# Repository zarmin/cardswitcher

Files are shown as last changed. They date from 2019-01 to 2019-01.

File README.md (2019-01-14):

# Card switcher

In some cases physical switching of a smart card is required to operate / test a system, this project can change between multiple smart cards electronically.

The device can be managed via a USB interface (Serial bus over USB).

_The project is inspired by [Smart Card removinator project](https://github.com/nkinder/smart-card-removinator)._

# Hardware

The device is made up from 3 different components: card shield, card controller, card adapter

## Card shield

One device installation can use multiple card shields, one card shield can take one card. The maximum number of stackable card shields are 15 (or 16, but w/o a unselected option). These shields are vertically stacked pcb modules.

Every shield have a 4 bit address, which can be changed by a dip switch on the board (the space between the stacked modules are enough to change the address after it stacked with a tweezer). The controller can detect address collisions via a feedback resistor.

Card shields can't detect if they have an inserted card or not.

### Card shield schematics

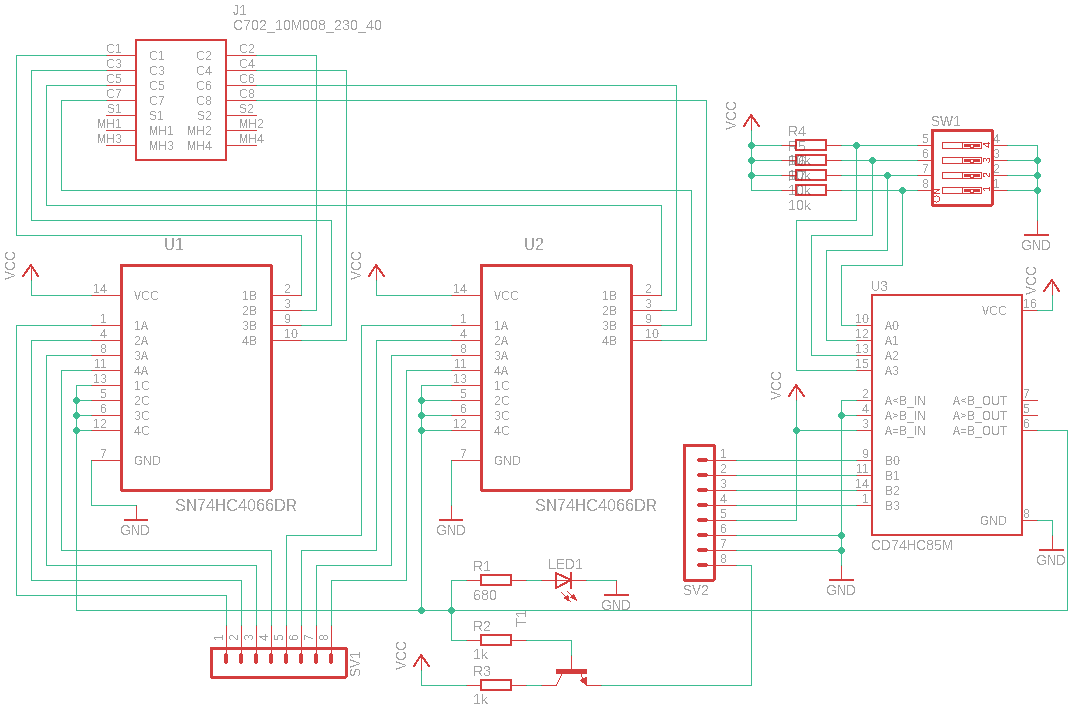
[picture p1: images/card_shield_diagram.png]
Card shield schematics


### Card shield PCB

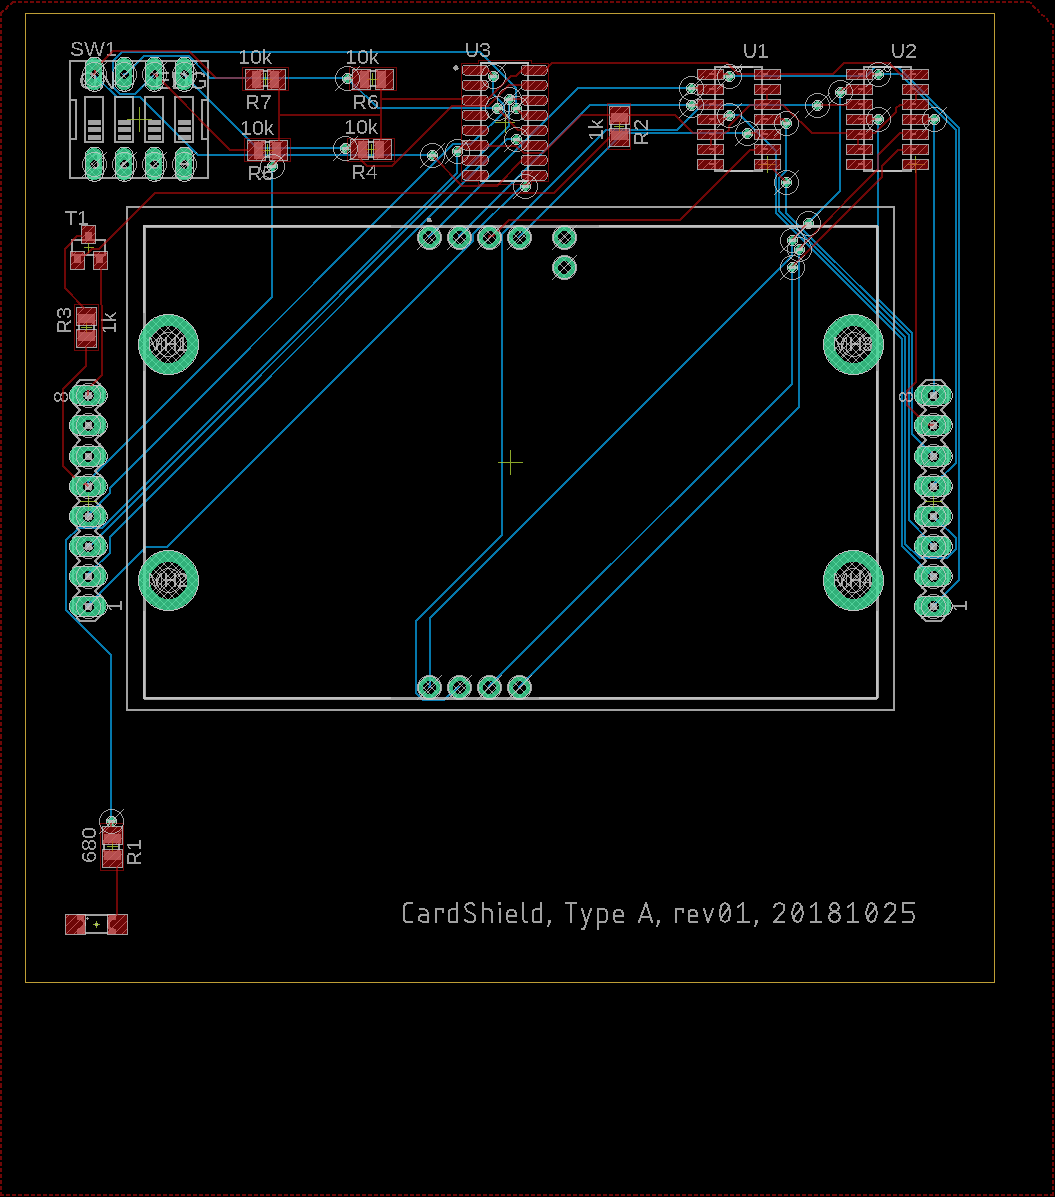
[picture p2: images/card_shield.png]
Card shield PBC


### Card shield photos

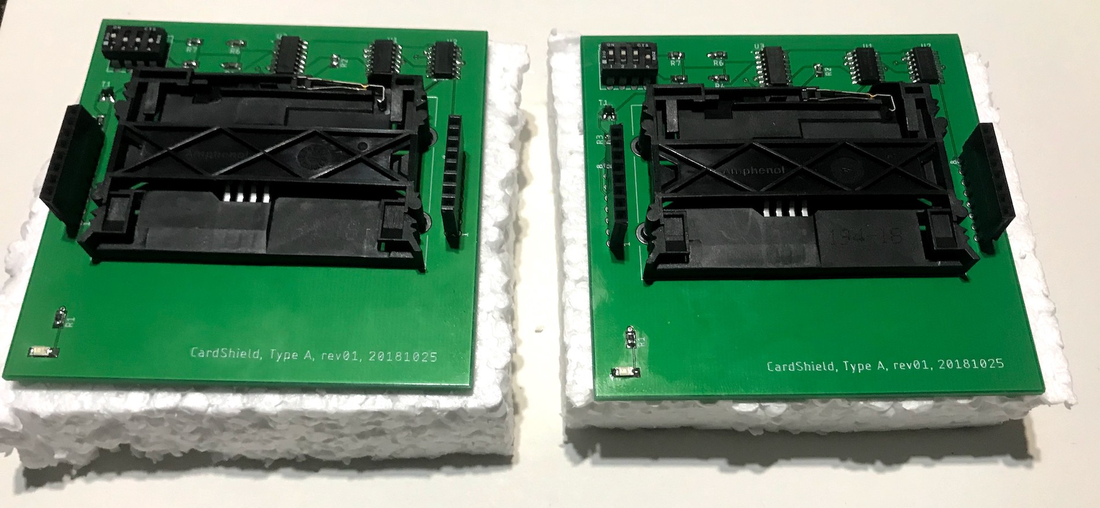
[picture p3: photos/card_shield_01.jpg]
Card shield photo


## Card controller

One device installation needs one controller. The controller will the base of the card shields.

The card controller can be controller (and powered) via mini USB. It connects to the card adapter with a ethernet cable (but not ethernet protocol of course).

It has an IC socket, initially designed to hold an ATMEGA168PA, with an Arduino software. The board also has a ISP connector to program the MCU.

### Card controller schematics

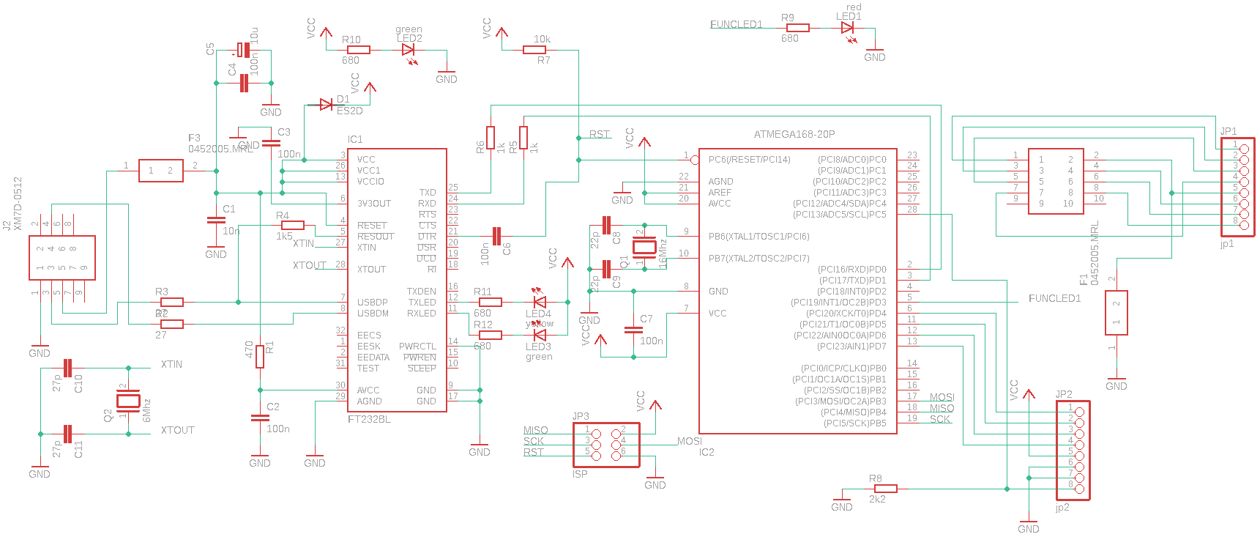
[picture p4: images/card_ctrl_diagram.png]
Card controller schematics


### Card controller PCB

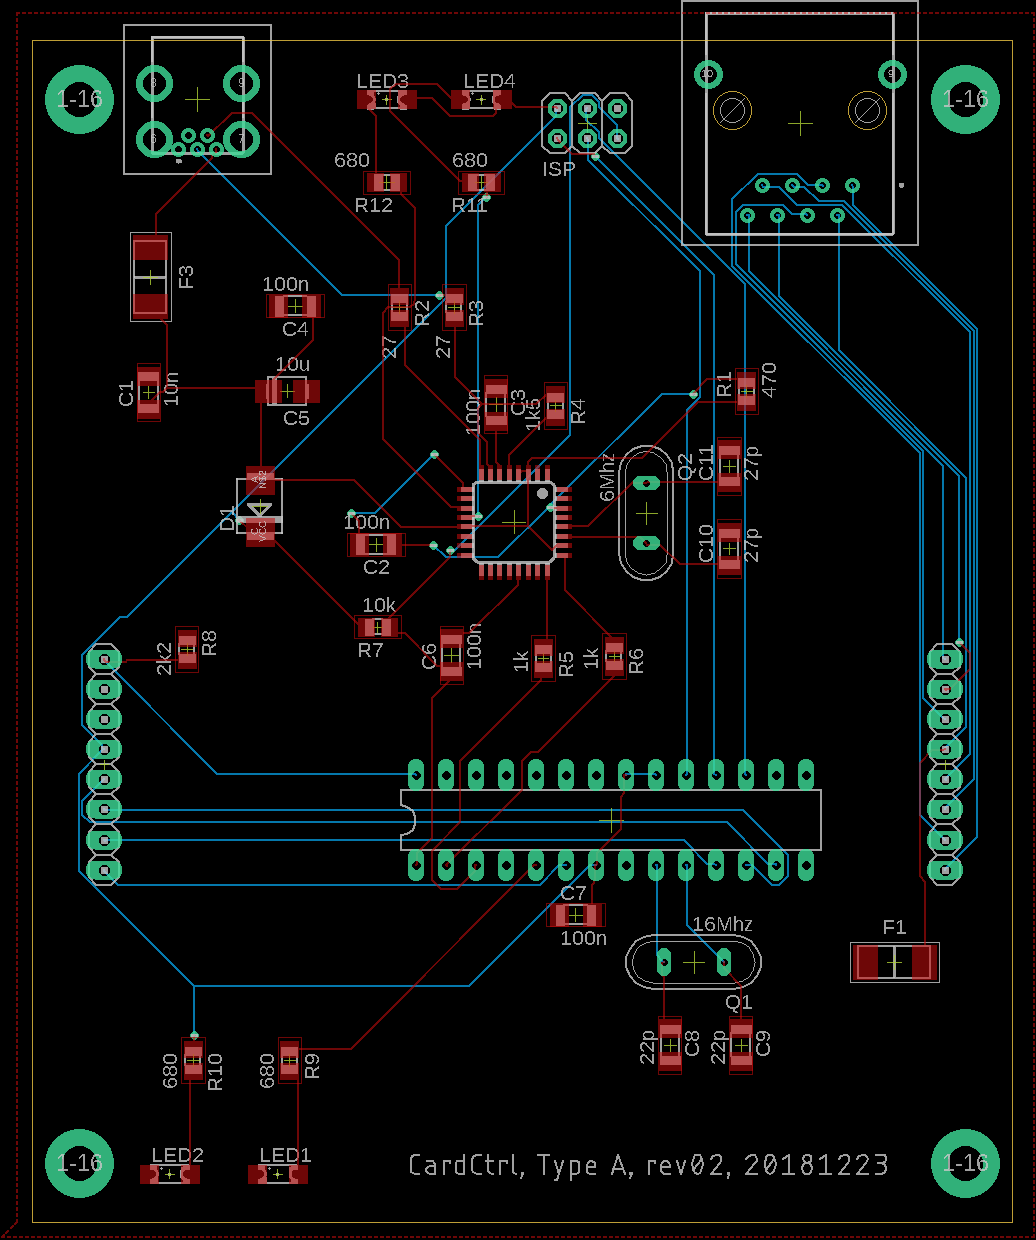
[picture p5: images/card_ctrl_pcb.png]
Card controller PCB


### Card controller photos

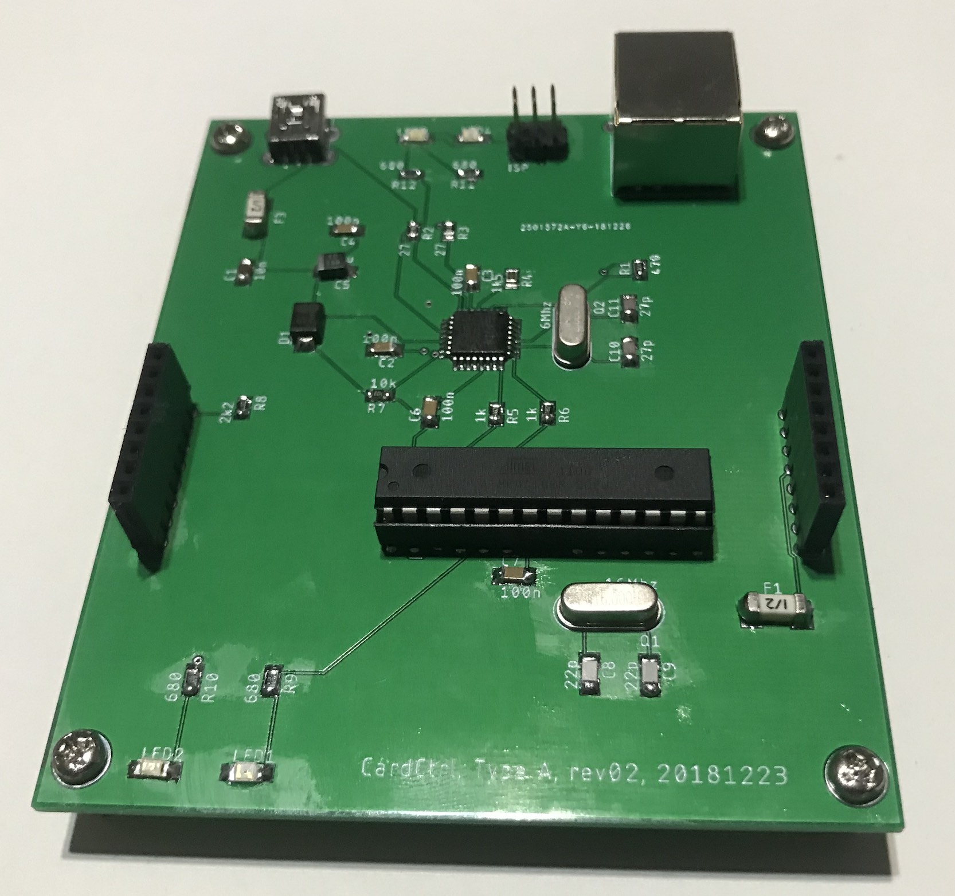
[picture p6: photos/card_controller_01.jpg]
Card controller photo

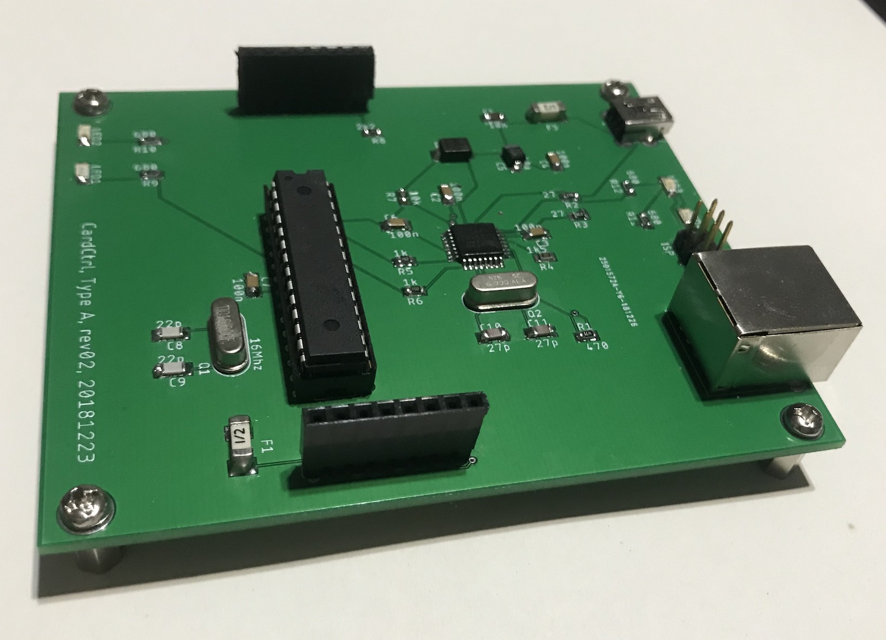
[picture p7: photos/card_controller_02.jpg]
Card controller photo


## Card adapter

The card adapter is the _fake_ card, that goes into the real card slot.

### Card adapter PCB

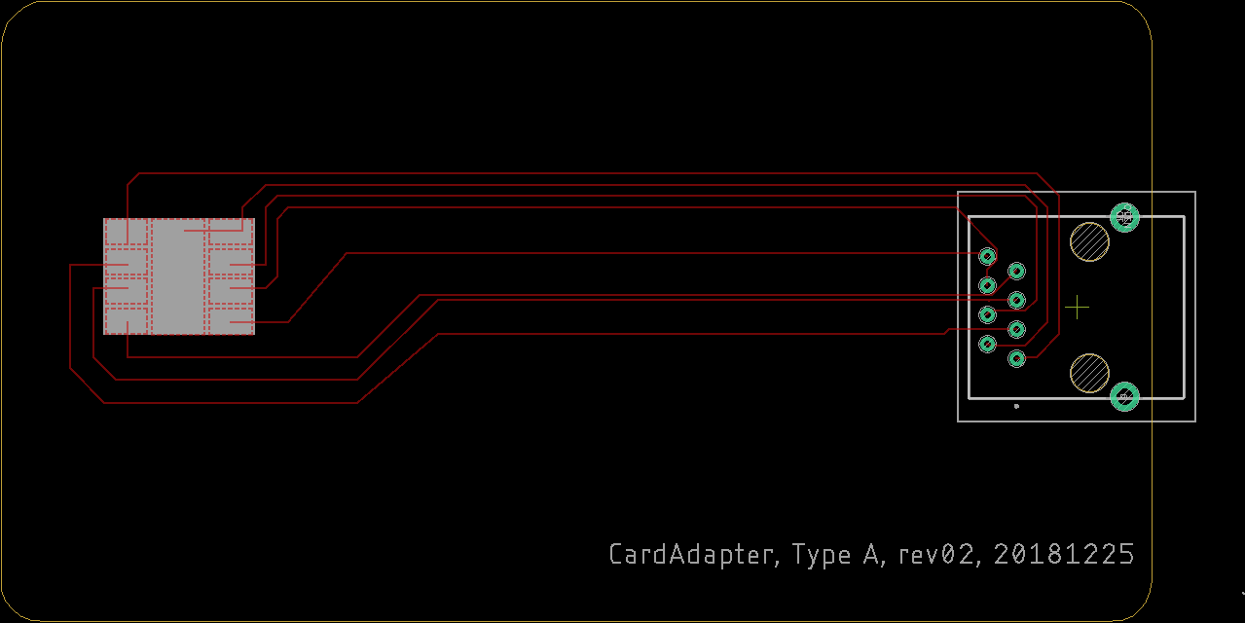
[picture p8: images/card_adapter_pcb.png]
Card adapter


### Card adapter photos

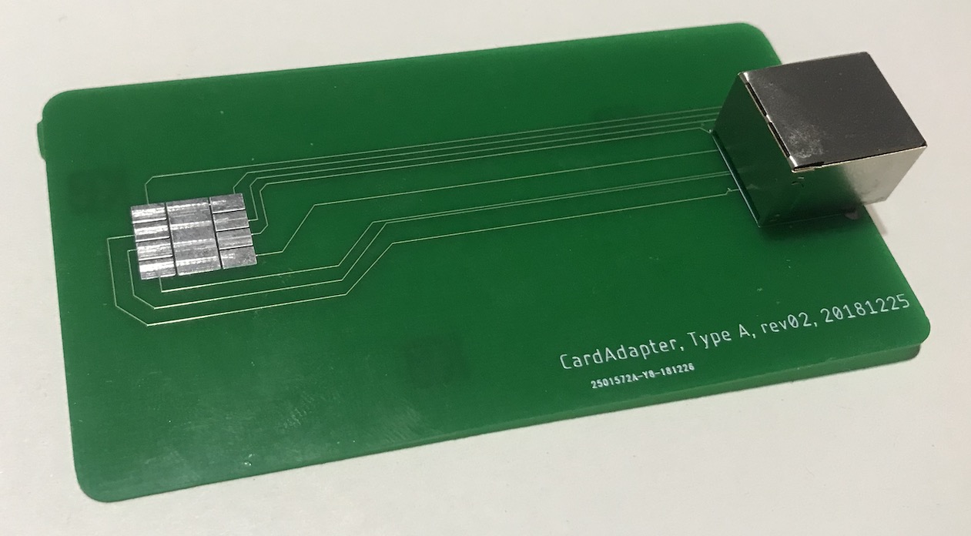
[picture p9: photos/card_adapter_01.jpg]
Card adapter photo

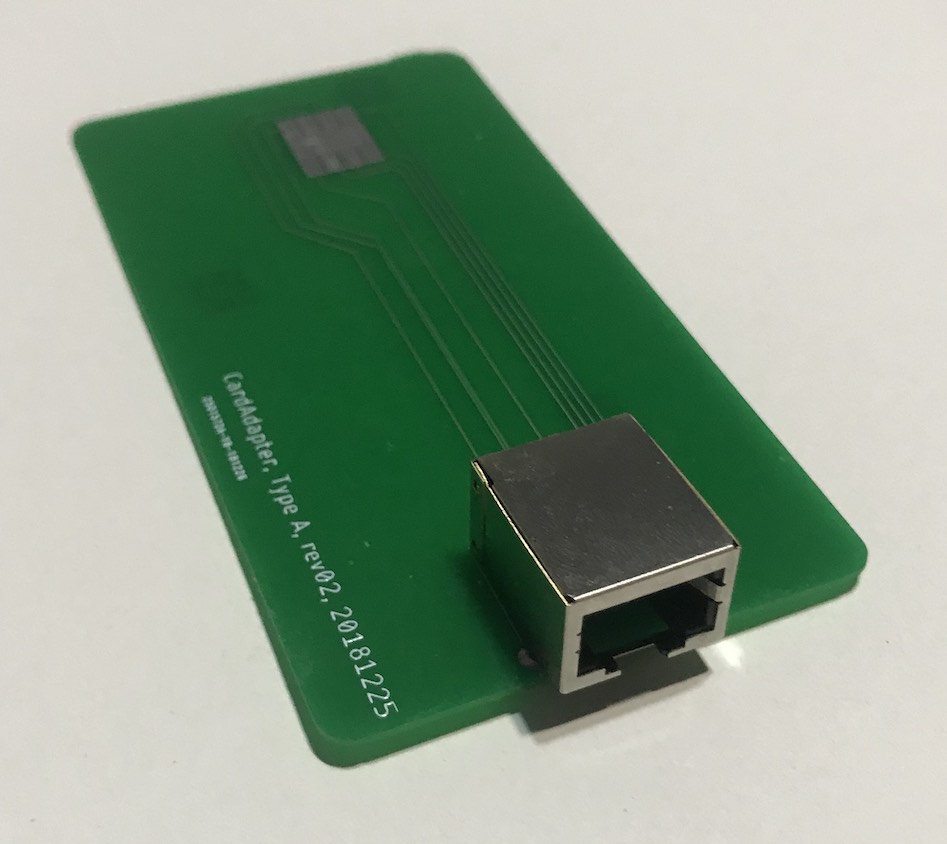
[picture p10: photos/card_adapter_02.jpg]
Card adapter photo


# Software

Software is in the mcu-software folder as an Arduino project. It can be uploaded via the USB interface or via the ISP. For the development the MiniCore Arduino board library used for the ATMega168IC (16 Mhz external clock; 168P / 168PA variant).

The software is checking the available card shield addresses upon boot and refuse to start (reboot loop with fast blinking of the activity LED) if an address collision is detected.
After the boot, it can be controlled via serial (via USB), by writing the addresses in ASCII (no newline required).

# Photos

_Installation with two card shield modules and cards_

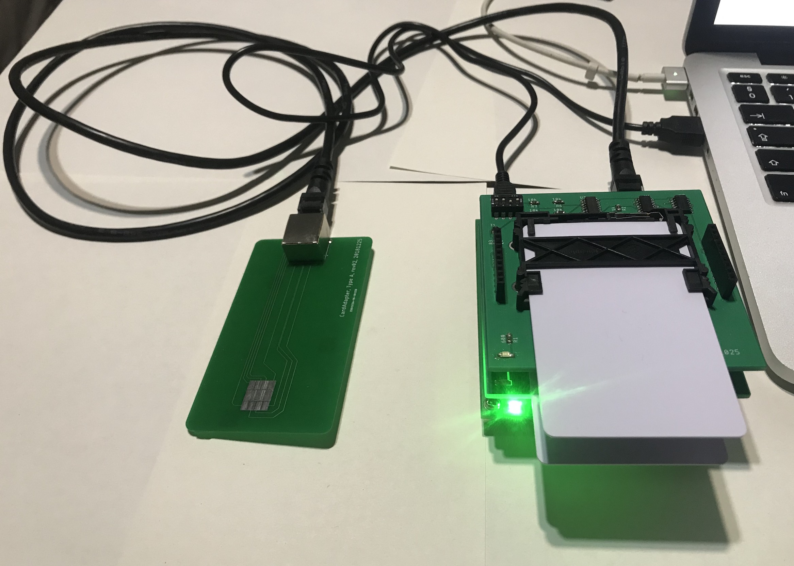
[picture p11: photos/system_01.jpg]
System with 2 cards

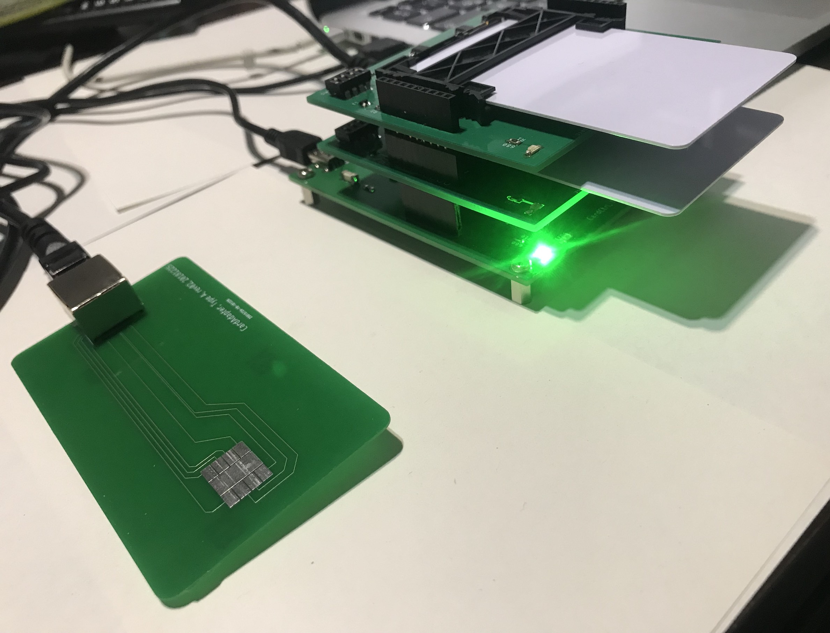
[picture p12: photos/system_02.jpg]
System with 2 cards

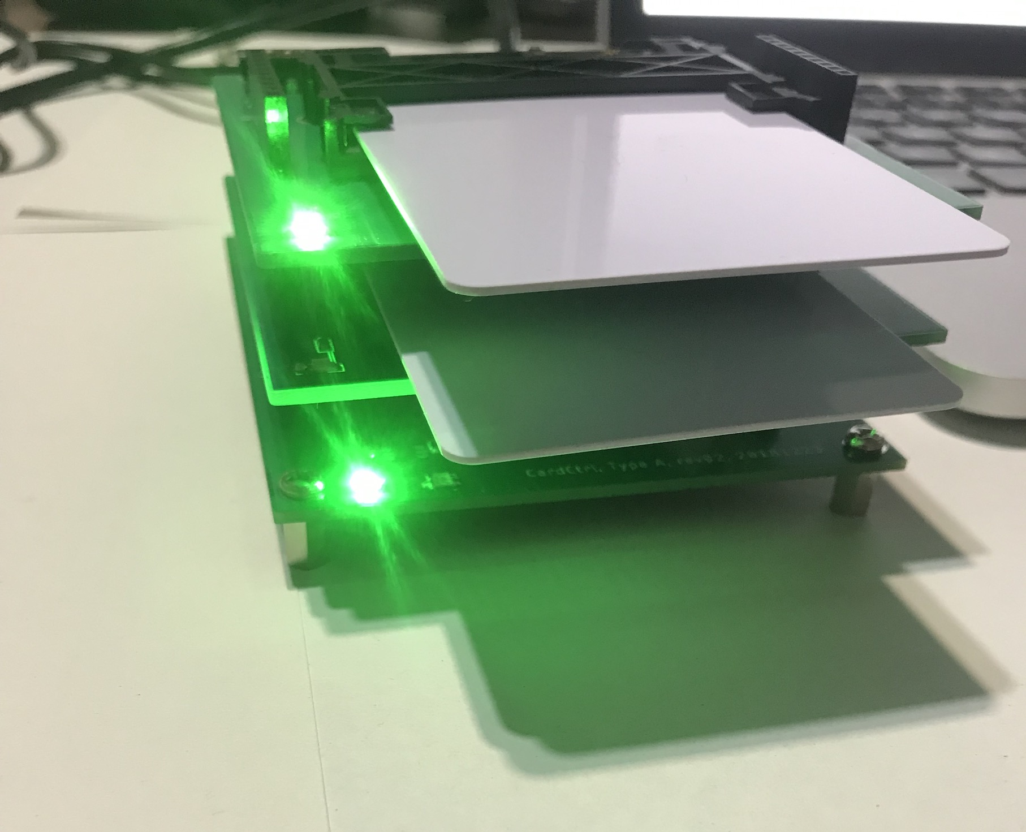
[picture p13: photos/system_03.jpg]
System with 2 cards


## Example terminal communication

```
Serial init
Device found on address: 1
Device found on address: 2
Ready to use!
Address? >>
Set to address (no active device): 4
Address? >>
Set to address (active device): 1
Address? >>
Set to address (active device): 2
Address? >>
```

# Components

The EAGLE files are containing the required components numbers (extra component libraries also included).

Special (non common / passive) components are:
- card shield: 2x SN74HC4066DR Quadruple Bilateral Analog Switch
- card shield: 1x CD74HC85M CMOS Logic 4-Bit Magnitude Comparator
- card shield: 1x C702 10M008 230 40 Amphenol Tuchel Smard card connector (Mouser)
- card controller: 1x FT232BL FTDI IC
- card controller: 1x ATMEGA168PA MCU

Every other component can be found in bom folder, or can be exported from EAGLE files.

# Isolation

The device using a common fused (500 mA) ground between the USB and the smart card adapter (Smart card connector GND). 

If complete isolation is required then an USB isolator (eg. Adafruit USB Isolator) can be used. The device should draw under 80 mA.

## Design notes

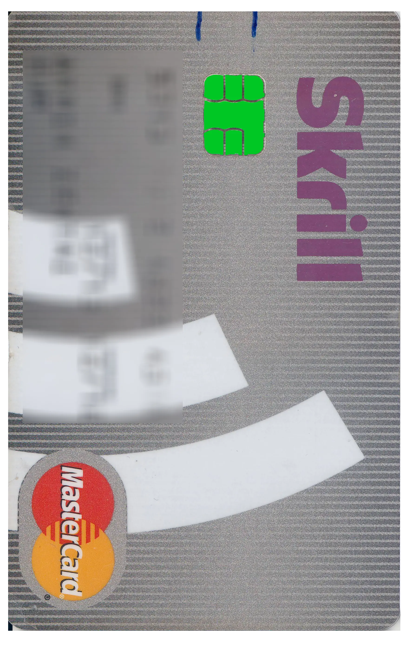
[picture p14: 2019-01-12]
cardmasks/base.webp

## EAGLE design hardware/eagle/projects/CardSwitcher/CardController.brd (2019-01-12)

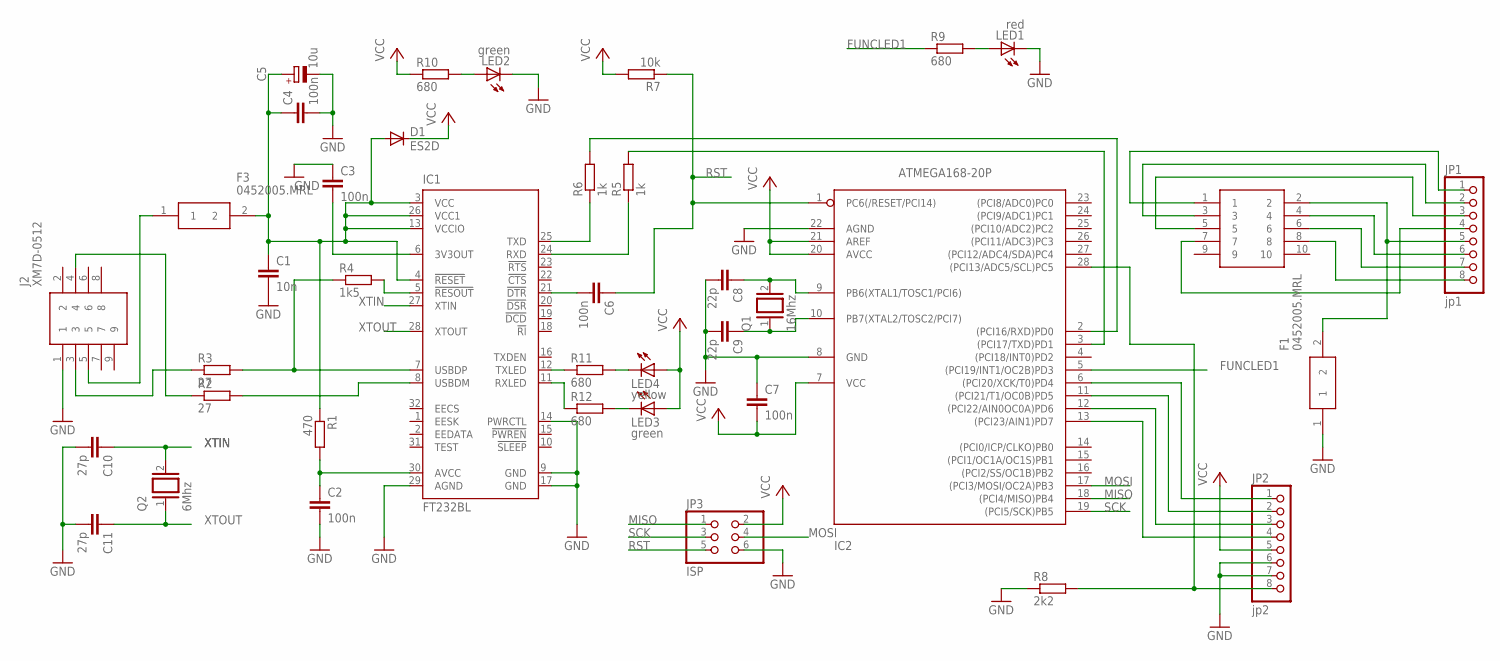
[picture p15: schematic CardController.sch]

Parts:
C1: 10n; C1206
C2, C3, C4, C6, C7: 100n; C1206
C5: 10u; B/3528-21W
C8, C9: 22p; C1206
C10, C11: 27p; C1206
D1: ES2D; SMB
F1, F3: 0452005.MRL; FUSC6127X294N
IC1: FT232BL; LQFP32-7X7
IC2: ATMEGA168-20P; DIL28-3
J1: 615008140121
J2: XM7D-0512; XM7D0512
JP1: jp1; 1X08
JP2: jp2; 1X08
JP3: ISP; 2X03
LED1: red; SML1206
LED2, LED3: green; SML1206
LED4: yellow; SML1206
Q1: 16Mhz; QS
Q2: 6Mhz; QS
R1: 470; R0805
R2, R3: 27; R0805
R4: 1k5; R0805
R5, R6: 1k; R0805
R7: 10k; R0805
R8: 2k2; R0805
R9, R10, R11, R12: 680; R0805

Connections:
FUNCLED1: IC2.5 ((PCI19/INT1/OC2B)PD3), R9.1
GND: C1.2, C2.2, C3.1, C4.2, C5.-, C7.1, C8.2, C9.2, C10.2, C11.2, F1.1, IC1.9 (GND), IC1.14 (PWRCTL), IC1.17 (GND), IC1.29 (AGND), IC2.8 (GND), IC2.22 (AGND), J2.1, JP2.6, JP2.7, JP3.6, LED1.C, LED2.C, R8.1
MISO: IC2.18 ((PCI4/MISO)PB4), JP3.1
MOSI: IC2.17 ((PCI3/MOSI/OC2A)PB3), JP3.4
unnamed: F3.1, J2.5
unnamed: C1.1, C4.1, C5.+, D1.A, F3.2, IC1.3 (VCC), IC1.4 (!RESET), IC1.13 (VCCIO), IC1.26 (VCC1), R1.1
unnamed: C2.1, IC1.30 (AVCC), R1.2
unnamed: C3.2, IC1.6 (3V3OUT)
unnamed: J2.4, R2.1
unnamed: IC1.8 (USBDM), R2.2
unnamed: J1.3, JP1.2
unnamed: IC1.5 (!RESOUT), R4.2
unnamed: IC1.25 (TXD), R6.1
unnamed: IC2.2 ((PCI16/RXD)PD0), R6.2
unnamed: IC2.13 ((PCI23/AIN1)PD7), JP2.4
unnamed: IC1.24 (RXD), R5.1
unnamed: C6.2, IC1.21 (!DTR)
unnamed: IC2.12 ((PCI22/AIN0OC0A)PD6), JP2.3
unnamed: C8.1, IC2.9 (PB6(XTAL1/TOSC1/PCI6)), Q1.2
unnamed: C9.1, IC2.10 (PB7(XTAL2/TOSC2/PCI7)), Q1.1
unnamed: IC2.28 ((PCI13/ADC5/SCL)PC5), JP2.8, R8.2
unnamed: IC1.12 (TXLED), R11.1
unnamed: LED1.A, R9.2
unnamed: J1.1, JP1.1
unnamed: IC2.3 ((PCI17/TXD)PD1), R5.2
unnamed: IC2.11 ((PCI21/T1/OC0B)PD5), JP2.2
unnamed: IC2.6 ((PCI20/XCK/T0)PD4), JP2.1
unnamed: J1.5, JP1.3
unnamed: J1.7, JP1.4
unnamed: F1.2, J1.2, JP1.5
unnamed: J1.4, JP1.6
unnamed: J1.6, JP1.7
unnamed: J1.8, JP1.8
unnamed: J2.3, R3.1
unnamed: LED2.A, R10.2
unnamed: IC1.11 (RXLED), R12.1
unnamed: LED4.C, R11.2
unnamed: LED3.C, R12.2
unnamed: IC1.7 (USBDP), R3.2, R4.1
RST: C6.1, IC2.1 (PC6(/RESET/PCI14)), JP3.5, R7.1
SCK: IC2.19 ((PCI5/SCK)PB5), JP3.3
VCC: C7.2, D1.C, IC2.7 (VCC), IC2.20 (AVCC), IC2.21 (AREF), JP2.5, JP3.2, LED3.A, LED4.A, R7.2, R10.1
XTIN: C10.1, IC1.27 (XTIN), Q2.2
XTOUT: C11.1, IC1.28 (XTOUT), Q2.1

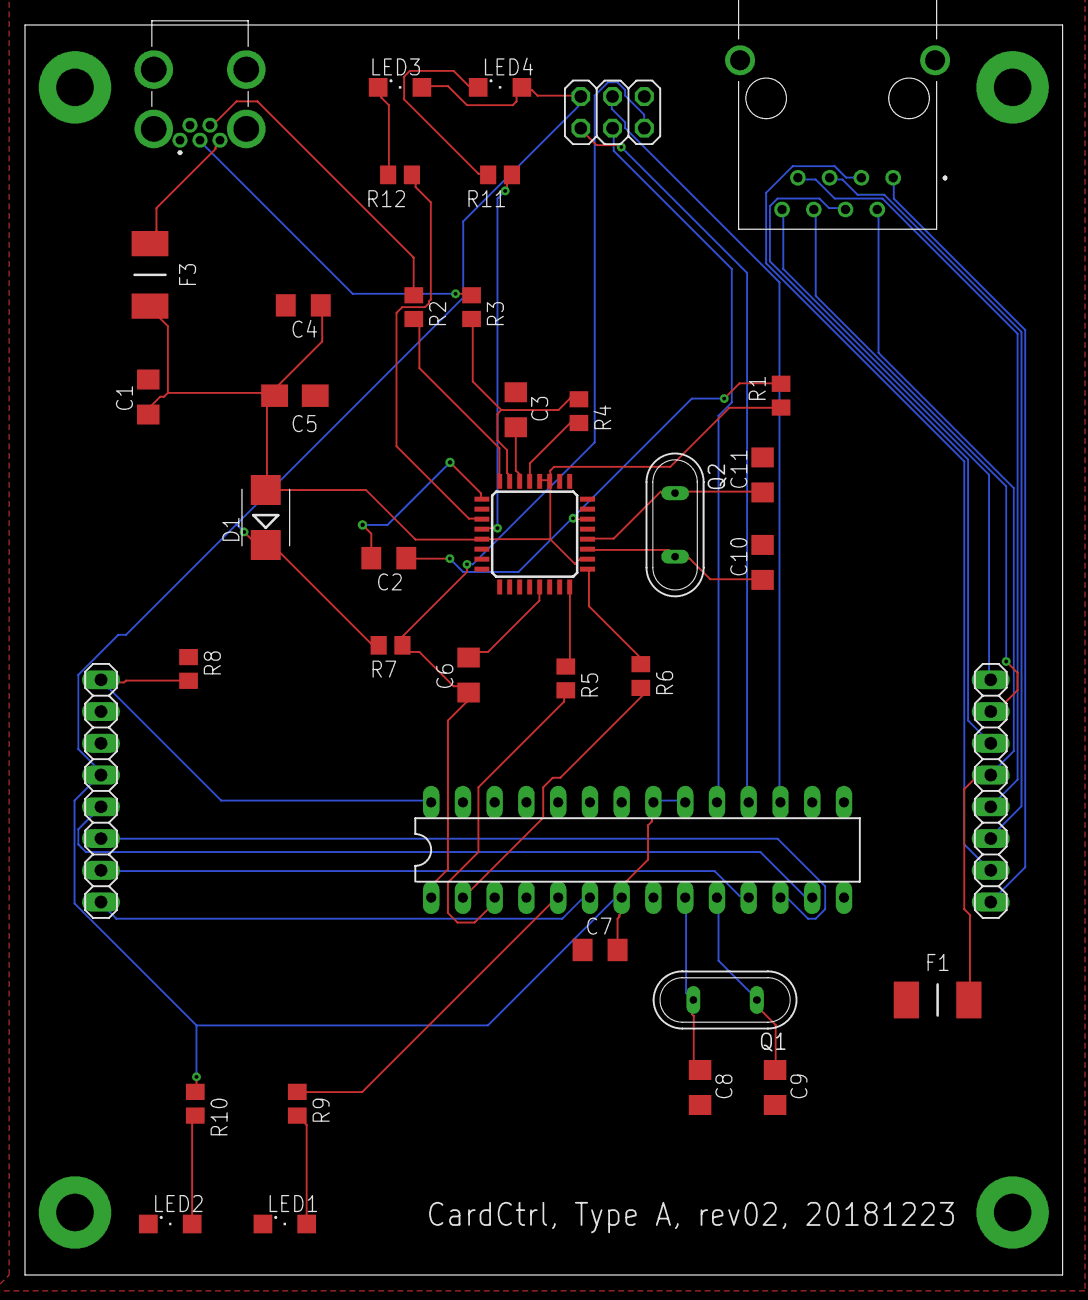
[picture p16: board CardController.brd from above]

Board: 2 copper layers, 83.0 x 100.0 mm, 39 parts (0 on the bottom side), 44 nets.

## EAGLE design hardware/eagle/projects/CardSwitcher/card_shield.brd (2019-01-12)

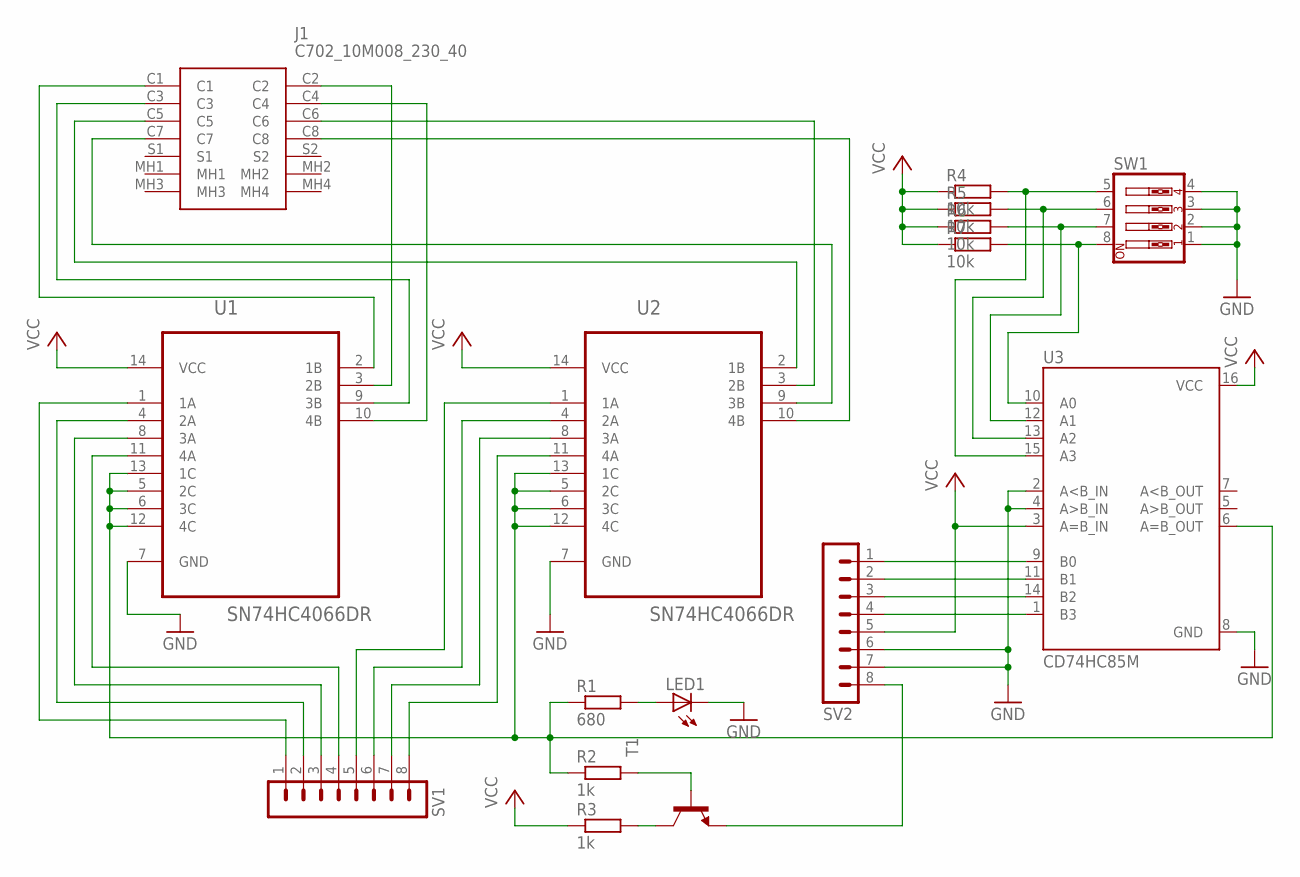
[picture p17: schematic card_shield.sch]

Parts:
J1: C702_10M008_230_40; C70210M00823040
LED1: LEDSML1206; SML1206
R1: 680; R0805
R2, R3: 1k; R0805
R4, R5, R6, R7: 10k; R0805
SV1, SV2: MA08-1
SW1: SW_DIP-4; EDG-04
T1: BC817-16-NPN-SOT23-BEC; SOT23-BEC
U1, U2: SN74HC4066DR; SOIC127P600X175-14N
U3: CD74HC85M; SOIC12P600X175-16N

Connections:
GND: LED1.C, SV2.6, SV2.7, SW1.1, SW1.2, SW1.3, SW1.4, U1.7 (GND), U2.7 (GND), U3.2 (A<B_IN), U3.4 (A>B_IN), U3.8 (GND)
unnamed: J1.C1, U1.2 (1B)
unnamed: J1.C3, U1.9 (3B)
unnamed: J1.C2, U1.3 (2B)
unnamed: J1.C4, U1.10 (4B)
unnamed: J1.C5, U2.2 (1B)
unnamed: J1.C6, U2.3 (2B)
unnamed: J1.C7, U2.9 (3B)
unnamed: J1.C8, U2.10 (4B)
unnamed: SV1.1, U1.1 (1A)
unnamed: SV1.2, U1.4 (2A)
unnamed: SV1.3, U1.8 (3A)
unnamed: SV1.4, U1.11 (4A)
unnamed: SV1.5, U2.1 (1A)
unnamed: SV1.6, U2.4 (2A)
unnamed: SV1.7, U2.8 (3A)
unnamed: SV1.8, U2.11 (4A)
unnamed: R1.1, R2.1, U1.5 (2C), U1.6 (3C), U1.12 (4C), U1.13 (1C), U2.5 (2C), U2.6 (3C), U2.12 (4C), U2.13 (1C), U3.6 (A=B_OUT)
unnamed: LED1.A, R1.2
unnamed: SV2.1, U3.9 (B0)
unnamed: R2.2, T1.B
unnamed: SV2.2, U3.11 (B1)
unnamed: SV2.3, U3.14 (B2)
unnamed: SV2.4, U3.1 (B3)
unnamed: R7.2, SW1.8, U3.10 (A0)
unnamed: R6.2, SW1.7, U3.12 (A1)
unnamed: R5.2, SW1.6, U3.13 (A2)
unnamed: R4.2, SW1.5, U3.15 (A3)
unnamed: R3.2, T1.C
unnamed: SV2.8, T1.E
VCC: R3.1, R4.1, R5.1, R6.1, R7.1, SV2.5, U1.14 (VCC), U2.14 (VCC), U3.3 (A=B_IN), U3.16 (VCC)

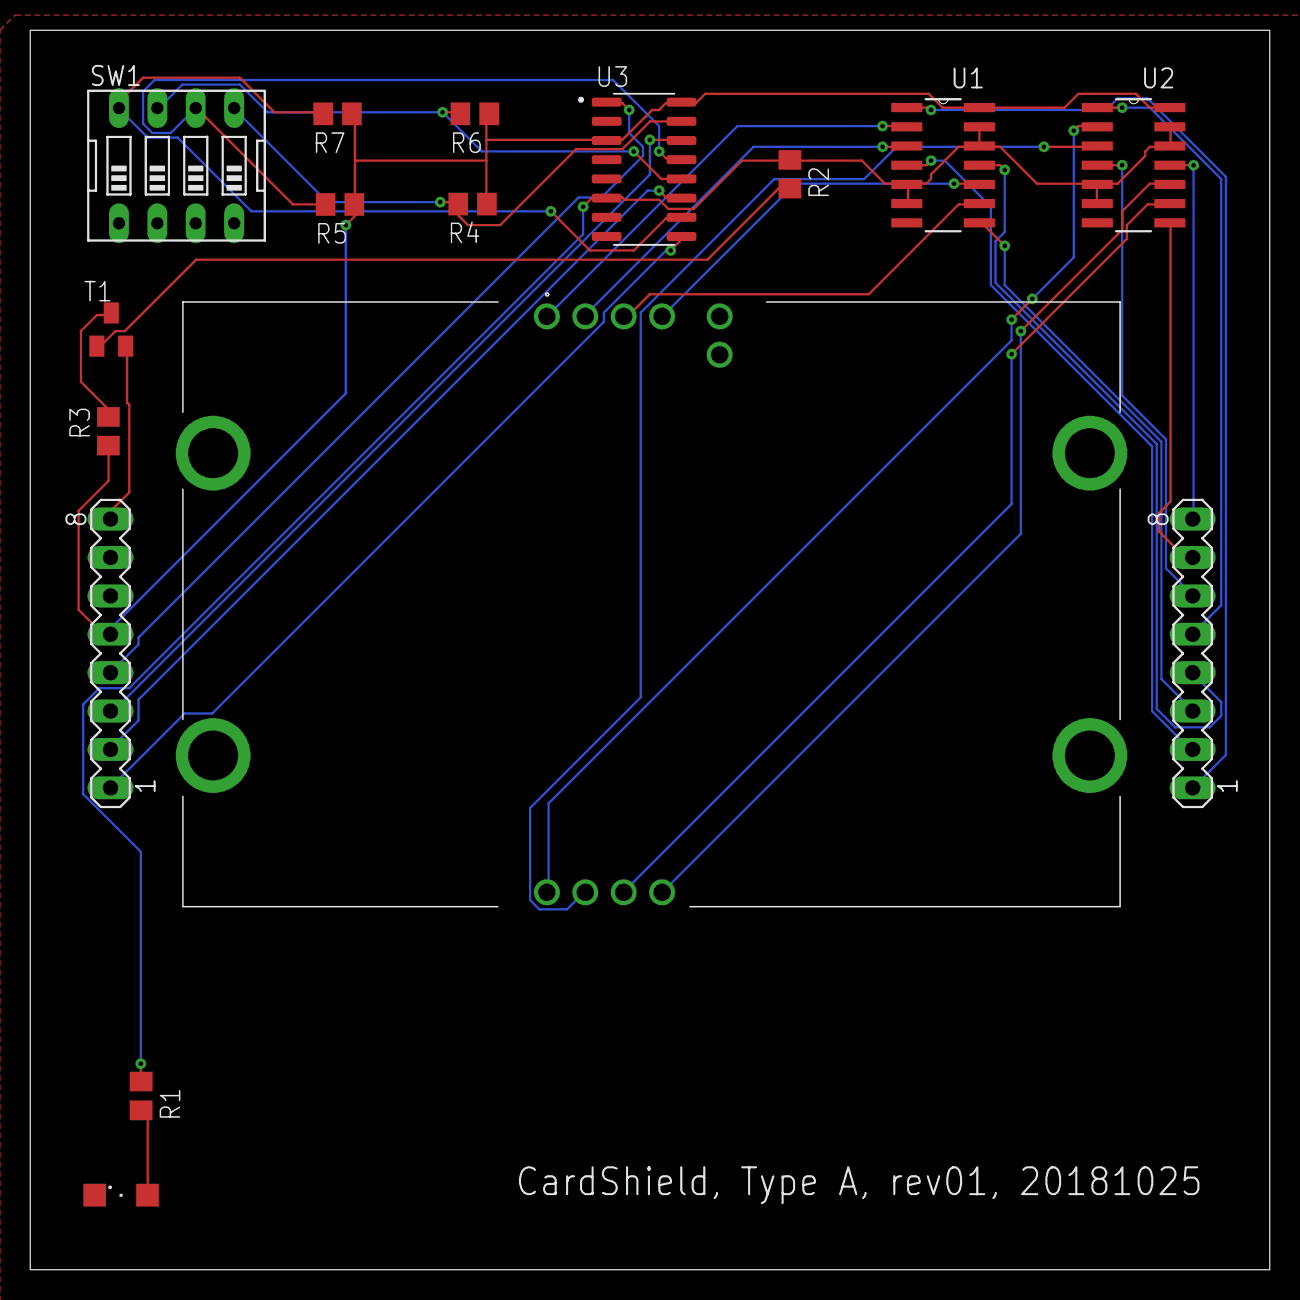
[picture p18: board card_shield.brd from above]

Board: 2 copper layers, 82.0 x 82.0 mm, 16 parts (0 on the bottom side), 31 nets.

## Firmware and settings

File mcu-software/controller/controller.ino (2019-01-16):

const char ADDR_BIT0 = 7;
const char ADDR_BIT1 = 6;
const char ADDR_BIT2 = 5;
const char ADDR_BIT3 = 4;
const char ACTIVITY_LED = 3;
const char ACTIVE_RESISTOR_APIN = 5;

const char ADDR_MAX = 15;


void(* resetFunc) (void) = 0; 

void pinSetup() {
  pinMode(ADDR_BIT0, OUTPUT);
  pinMode(ADDR_BIT1, OUTPUT);
  pinMode(ADDR_BIT2, OUTPUT);
  pinMode(ADDR_BIT3, OUTPUT);

  pinMode(ACTIVITY_LED, OUTPUT);  


  digitalWrite(ADDR_BIT0, LOW);
  digitalWrite(ADDR_BIT1, LOW);
  digitalWrite(ADDR_BIT2, LOW);
  digitalWrite(ADDR_BIT3, LOW);

  digitalWrite(ACTIVITY_LED, LOW);
}

void errorDisplay() {
  Serial.println("Error occured, resetting in 6 seconds...");
  
  for (int i = 0; i < 6*10; i++) {
    digitalWrite(ACTIVITY_LED, HIGH);
    delay(50);
    digitalWrite(ACTIVITY_LED, LOW);
    delay(50);
  }

  Serial.println("RESET!");
  delay(500);
}

bool setAddress(char addr) {
  if (addr > ADDR_MAX) {
    return false;
  }
  
  digitalWrite(ADDR_BIT3, (addr & 8) ? HIGH : LOW);    
  digitalWrite(ADDR_BIT2, (addr & 4) ? HIGH : LOW);
  digitalWrite(ADDR_BIT1, (addr & 2) ? HIGH : LOW);
  digitalWrite(ADDR_BIT0, (addr & 1) ? HIGH : LOW); 

  return true;
}

// returns 
//  0: if zero device active
//  1: if one device active
//  2: if 2 or more device active
//  -1: if something wrong happened
char checkActiveDevices() {
  int val = analogRead(ACTIVE_RESISTOR_APIN); // 10 bit precision, 0 - 1023

  // nothing selected: pulled down to 0
  if (val < 100) { // should be low
    return 0;
  }

  // 1 selected: measured between: 1k + NPN T voltage drop (~0.24V) AND 2.2k  
  // calculated to approx (3.33 / 4.54) * 1024 = 751 
  // checking with 4% of precision
  if (val > 721 && val < 780) {
    return 1;
  } else if (val >= 780) { // more than 2 selected
    return 2;
  } else { // between 100 and 720 -> undefined state
    return -1;
  }
}

void systemCheck() {
  digitalWrite(ACTIVITY_LED, HIGH);
  
  char activeDevices[16] = {0, 0, 0, 0, 0, 0, 0, 0, 0, 0, 0, 0, 0, 0, 0, 0};
  bool error = false;
  
  for (int i = 0; i <= ADDR_MAX; i++) {
    setAddress(i);
    char activeDevice = checkActiveDevices();

    if (activeDevice == 0) {
      // no device found, skip
    } else if (activeDevice == 1) {
      // valid active device
      activeDevices[i] = 1;
    } else if (activeDevice >= 2) {
      Serial.print("Collision on address: ");
      Serial.println(i, DEC);
      error = true;
    } else {
      Serial.print("Unexpected error while checking address (invalid resistor value): ");
      Serial.println(i, DEC);
      error = true;
    }
  }

  if (error) {
    errorDisplay();
    resetFunc();
    return;
  }

  for (int i = 0; i <= ADDR_MAX; i++) {
    if (activeDevices[i] == 1) {
      Serial.print("Device found on address: ");
      Serial.println(i, DEC);
    }
  }

  // blink one the activity led
  digitalWrite(ACTIVITY_LED, LOW);
  delay(500);
  digitalWrite(ACTIVITY_LED, HIGH);
  delay(500);
  digitalWrite(ACTIVITY_LED, LOW);
  
  Serial.println("Ready to use!");
}

void prompt() {
  Serial.print("Address? >> ");
}

void setup() {
  pinSetup();

  Serial.begin(9600);
  Serial.println("Serial init");

  systemCheck();

  prompt();
}

String inString = "";

void loop() {    
  char address = -1;
  
  while (Serial.available() > 0) {
    int inChar = Serial.read();    

    if (isDigit(inChar) || isAlpha(inChar)) {
      Serial.print((char)inChar); // echo
      inString += (char)inChar;
    }    
    if (inString.length() > 8) {
      inString = "";
      return;
    }
    if (inChar == '\n') {      
      if (inString.equalsIgnoreCase("reset")) {
        resetFunc();
        return;
      }
      address = (char)inString.toInt();
      inString = "";
      break; 
    }
  }
  
  if (address == -1) {
    delay(5);
    return;
  }

  digitalWrite(ACTIVITY_LED, HIGH);

  Serial.println();

  if (address > ADDR_MAX) {
    Serial.println("Address out of range");
    return;
  }

  setAddress(address);

  char activeDevice = checkActiveDevices();

  if (activeDevice == 0) {
    Serial.print("Set to address (no active device): ");
    Serial.println(address, DEC);
  } else if (activeDevice == 1) {
    Serial.print("Set to address (active device): ");
    Serial.println(address, DEC);
  } else if (activeDevice >= 2) {
    Serial.print("!!WARNING!! Set to address (MULTIPLE ACTIVE DEVICES, COLLISION DETECTED!): ");
    Serial.println(address, DEC);
  } else {
    Serial.print("!!ERROR!! Unexpected error while checking address (invalid resistor value): ");
    Serial.println(address, DEC);    
  }

  digitalWrite(ACTIVITY_LED, LOW);

  prompt();
}  
